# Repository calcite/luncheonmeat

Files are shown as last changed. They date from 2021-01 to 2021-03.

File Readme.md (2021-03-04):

# luncheonmeat

## Hardware

Device PCB was designed using KiCAD 5.1. For more info visit KiCAD website [kicad.org](https://kicad.org/download/) 

## Firmware

### Dependencies

```shell
sudo apt-get install gcc-avr binutils-avr avr-libc gdb-avr avrdude
```

> Note: ``ATMega328PB`` is new revision from 2017. avr-libc may not have support for this device. To add support please see how its done in .devcontainer/Dockerfile.

### Build

```shell
cd firmware
make
```

### Flashing

Flashing the device using AVR Dragon ISP:

```shell
make program
```

Set fuses **this is done only once**:

```shell
make program-fuses
```

> Note: ``make`` will internally run ``avrdude`` with correct atributes. 

Bare avrdude flashing command:

```shell
avrdude -p atmega328pb -P usb -c dragon_isp    -U flash:w:luncheonmeat.hex -U eeprom:w:luncheonmeat.eep
```

### Serial Bootloader

Generating ``defines.h`` file:
```shell
cd firmware/bootloader
./preprocessor.sh atmega328pb 2048 PORTB PINB0 8000000 19200
make
make program
make program-fuses
```

Reading target fuses:
```shell
avrdude -p atmega328pb -P usb -c dragon_isp -U efuse:r:-:h
```

To enter bootloader hold ''5'' button and reset the device.

## Resources

- [fuses calculator](http://eleccelerator.com/fusecalc/fusecalc.php?chip=atmega328p&LOW=E2&HIGH=D8&EXTENDED=F7&LOCKBIT=FF)

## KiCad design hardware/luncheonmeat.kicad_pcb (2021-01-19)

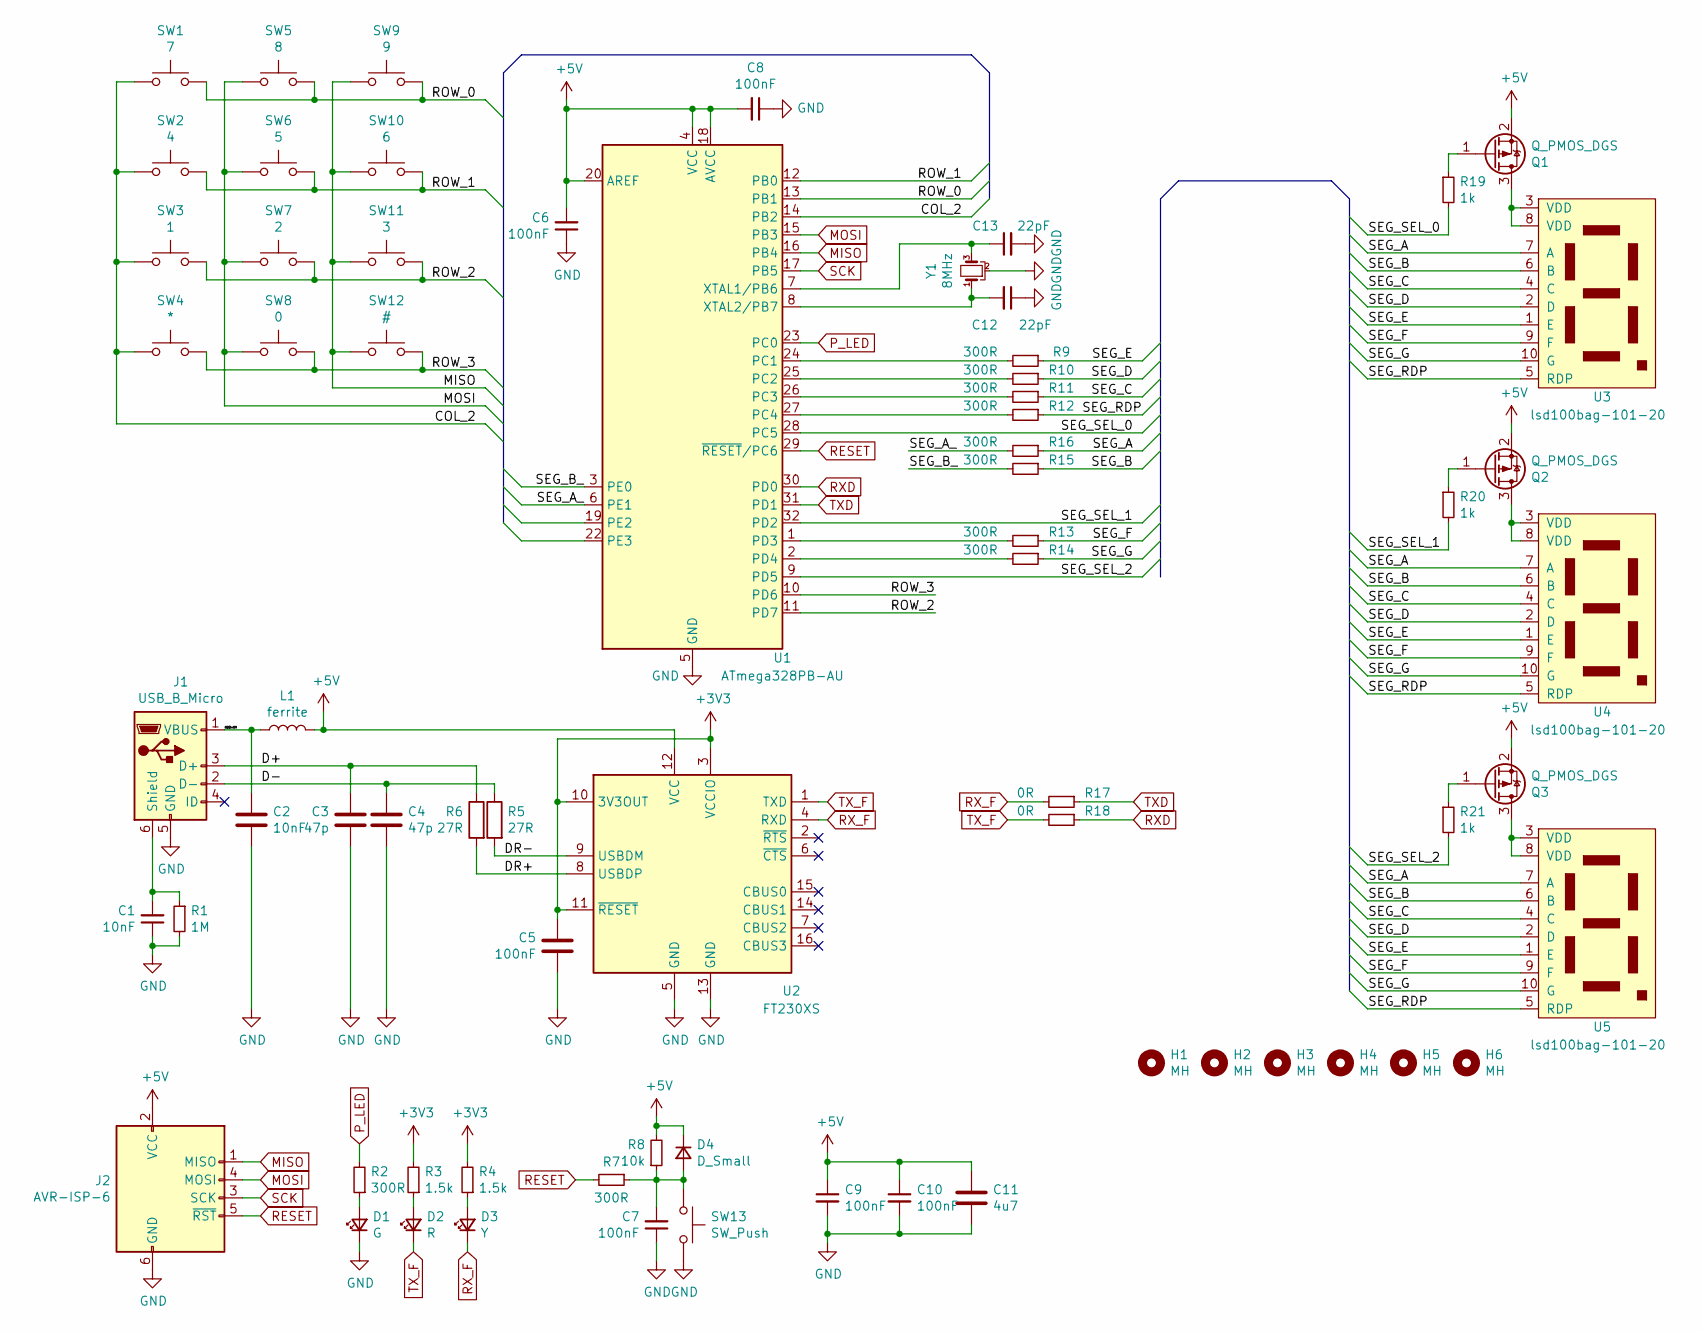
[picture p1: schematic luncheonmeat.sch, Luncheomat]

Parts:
C1, C2: 10nF; C_0805_2012Metric_Pad1.18x1.45mm_HandSolder
C3, C4: 47p; C_0805_2012Metric_Pad1.18x1.45mm_HandSolder
C5, C6, C7, C8, C9, C10: 100nF; C_0805_2012Metric_Pad1.18x1.45mm_HandSolder
C11: 4u7; C_0603_1608Metric_Pad1.05x0.95mm_HandSolder
C12, C13: 22pF; C_0603_1608Metric_Pad1.08x0.95mm_HandSolder
D1: G; LED_0805_2012Metric_Castellated
D2: R; LED_0805_2012Metric_Castellated
D3: Y; LED_0805_2012Metric_Castellated
D4: D_Small; D_0805_2012Metric
H1, H2, H3, H4, H5, H6: MH; MountingHole_3.2mm_M3_DIN965
J1: USB_B_Micro; USB_Micro-B_Wuerth_629105150521_CircularHoles
J2: AVR-ISP-6; IDC-Header_2x03_P2.54mm_Vertical
L1: ferrite; L_0805_2012Metric_Pad1.15x1.40mm_HandSolder
Q1, Q2, Q3: Q_PMOS_DGS; SOT-23
R1: 1M; R_0805_2012Metric_Pad1.20x1.40mm_HandSolder
R2, R7, R9, R10, R11, R12, R13, R14, R15, R16: 300R; R_0805_2012Metric_Pad1.20x1.40mm_HandSolder
R3, R4: 1.5k; R_0805_2012Metric_Pad1.20x1.40mm_HandSolder
R5, R6: 27R; R_0805_2012Metric_Pad1.20x1.40mm_HandSolder
R8: 10k; R_0805_2012Metric_Pad1.20x1.40mm_HandSolder
R17, R18: 0R; R_0805_2012Metric_Pad1.20x1.40mm_HandSolder
R19, R20, R21: 1k; R_0805_2012Metric_Pad1.20x1.40mm_HandSolder
SW1: 7; SW_PUSH_6mm
SW2: 4; SW_PUSH_6mm
SW3: 1; SW_PUSH_6mm
SW4: *; SW_PUSH_6mm
SW5: 8; SW_PUSH_6mm
SW6: 5; SW_PUSH_6mm
SW7: 2; SW_PUSH_6mm
SW8: 0; SW_PUSH_6mm
SW9: 9; SW_PUSH_6mm
SW10: 6; SW_PUSH_6mm
SW11: 3; SW_PUSH_6mm
SW12: #; SW_PUSH_6mm
SW13: SW_Push; SW_Push_1P1T_NO_CK_KSC7xxJ
U1: ATmega328PB-AU; TQFP-32_7x7mm_P0.8mm
U2: FT230XS; SSOP-16_3.9x4.9mm_P0.635mm
U3, U4, U5: lsd100bag-101-20; lsd100bag-101
Y1: 8MHz; Crystal_SMD_0603-4Pin_6.0x3.5mm_HandSoldering

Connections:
+3V3: C5.2, R3.2, R4.2, U2.3 (VCCIO), U2.10 (3V3OUT), U2.11 (~RESET)
+5V: C6.2, C8.2, C9.1, C10.1, C11.1, D4.1 (K), J2.2 (VCC), L1.2, Q1.2 (S), Q2.2 (S), Q3.2 (S), R8.2, U1.4 (VCC), U1.18 (AVCC), U1.20 (AREF), U2.12 (VCC)
/COL_2: SW1.2, SW2.2, SW3.2, SW4.2, U1.14 (PB2)
/D+: C3.2, J1.3 (D+), R6.1
/D-: C4.1, J1.2 (D-), R5.1
/DR+: R6.2, U2.8 (USBDP)
/DR-: R5.2, U2.9 (USBDM)
/ROW_0: SW1.1, SW5.1, SW9.1, U1.13 (PB1)
/ROW_1: SW2.1, SW6.1, SW10.1, U1.12 (PB0)
/ROW_2: SW3.1, SW7.1, SW11.1, U1.11 (PD7)
/ROW_3: SW4.1, SW8.1, SW12.1, U1.10 (PD6)
/SEG_A: R16.1, U3.7 (A), U4.7 (A), U5.7 (A)
/SEG_A_: R16.2, U1.6 (PE1)
/SEG_B: R15.1, U3.6 (B), U4.6 (B), U5.6 (B)
/SEG_B_: R15.2, U1.3 (PE0)
/SEG_C: R11.1, U3.4 (C), U4.4 (C), U5.4 (C)
/SEG_D: R10.1, U3.2 (D), U4.2 (D), U5.2 (D)
/SEG_E: R9.1, U3.1 (E), U4.1 (E), U5.1 (E)
/SEG_F: R13.1, U3.9 (F), U4.9 (F), U5.9 (F)
/SEG_G: R14.1, U3.10 (G), U4.10 (G), U5.10 (G)
/SEG_RDP: R12.1, U3.5 (RDP), U4.5 (RDP), U5.5 (RDP)
/SEG_SEL_0: R19.2, U1.28 (PC5)
/SEG_SEL_1: R20.2, U1.32 (PD2)
/SEG_SEL_2: R21.2, U1.9 (PD5)
/USB+5V: C2.2, J1.1 (VBUS), L1.1
GND: C1.1, C2.1, C3.1, C4.2, C5.1, C6.1, C7.1, C8.1, C9.2, C10.2, C11.2, C12.1, C13.2, D1.1 (K), J1.5 (GND), J2.6 (GND), R1.2, SW13.2, U1.5 (GND), U1.21 (GND), U2.5 (GND), U2.13 (GND), Y1.2
MISO: J2.1 (MISO), SW9.2, SW10.2, SW11.2, SW12.2, U1.16 (PB4)
MOSI: J2.4 (MOSI), SW5.2, SW6.2, SW7.2, SW8.2, U1.15 (PB3)
unnamed: C1.2, J1.6 (Shield), R1.1
unnamed: C7.2, D4.2 (A), R7.1, R8.1, SW13.1
unnamed: C12.2, U1.8 (XTAL2/PB7), Y1.1
unnamed: C13.1, U1.7 (XTAL1/PB6), Y1.3
unnamed: D1.2 (A), R2.1
unnamed: D2.2 (A), R3.1
unnamed: D3.2 (A), R4.1
unnamed: Q1.1 (G), R19.1
unnamed: Q1.3 (D), U3.3 (VDD), U3.8 (VDD)
unnamed: Q2.1 (G), R20.1
unnamed: Q2.3 (D), U4.3 (VDD), U4.8 (VDD)
unnamed: Q3.1 (G), R21.1
unnamed: Q3.3 (D), U5.3 (VDD), U5.8 (VDD)
unnamed: R9.2, U1.24 (PC1)
unnamed: R10.2, U1.25 (PC2)
unnamed: R11.2, U1.26 (PC3)
unnamed: R12.2, U1.27 (PC4)
unnamed: R13.2, U1.1 (PD3)
unnamed: R14.2, U1.2 (PD4)
P_LED: R2.2, U1.23 (PC0)
RESET: J2.5 (~RST), R7.2, U1.29 (~RESET~/PC6)
RXD: R18.1, U1.30 (PD0)
RX_F: D3.1 (K), R17.2, U2.4 (RXD)
SCK: J2.3 (SCK), U1.17 (PB5)
TXD: R17.1, U1.31 (PD1)
TX_F: D2.1 (K), R18.2, U2.1 (TXD)

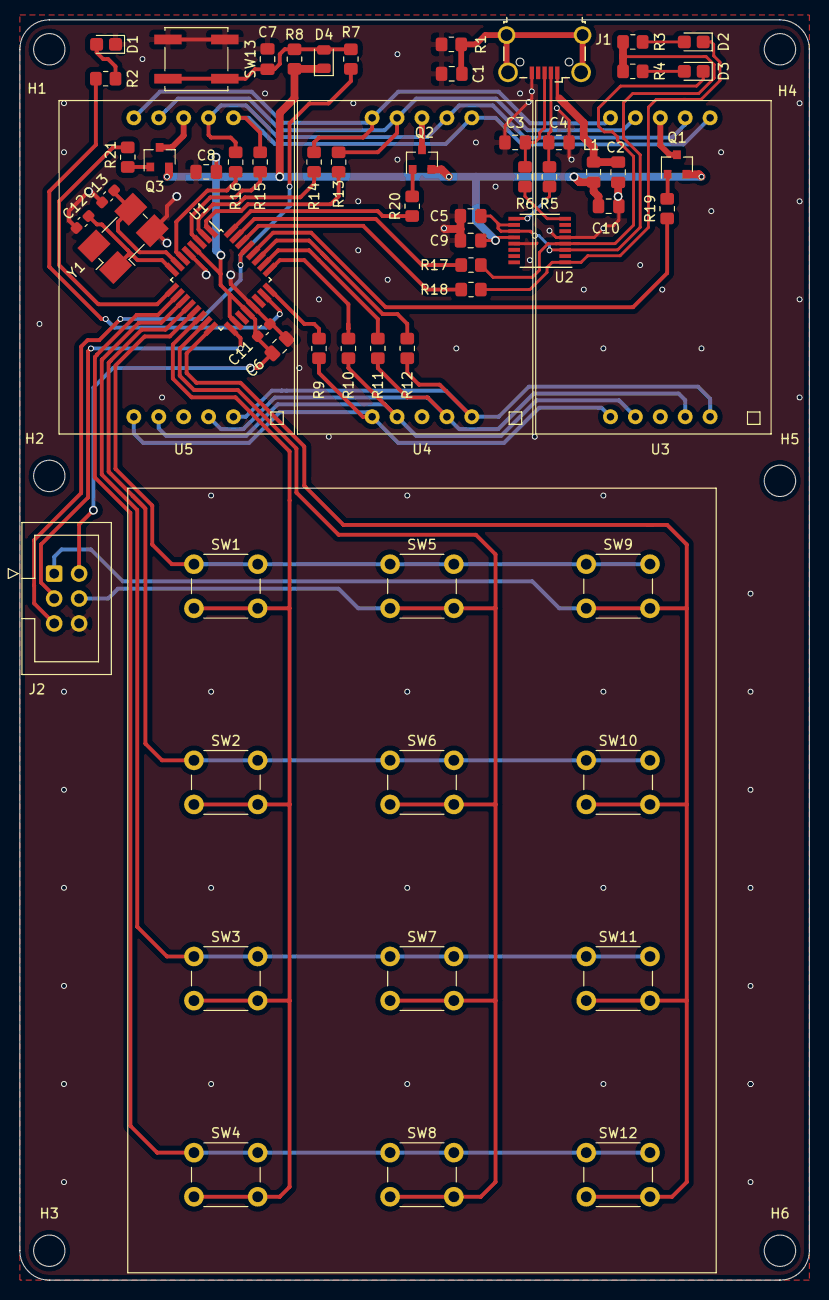
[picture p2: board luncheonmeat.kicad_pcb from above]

Board: 2 copper layers, 80.5 x 128.5 mm, 69 parts (0 on the bottom side), 54 nets.

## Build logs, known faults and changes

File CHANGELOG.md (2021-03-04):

# CHANGELOG

## v0.4.4 [2021/03/04]

- added AVR109 bootloader.

## v0.4.3 [2021/03/04]

- allow to send single zero.
- add clear command send on clear button long push.

## v0.4.2 [2021/03/03]

- fix zero imput handling, when zero is imputed as first character.

## v0.4.1 [2021/02/22]

- fix multiplex for animations and special characters.

## v0.4.0 [2021/02/22]

- segments inverted to back side.
- keypad mapping changed to mobile phone layout.
- maximum of 3 digits can be imputed at the time. (There is no owerflow)
- variable single digit multiplex to increase brightness.

## v0.3.0 [2021/02/18]

First firmware release. This release includes:

- 7 segment display driver.
- key matrix readout.
- USART driver and simple transport packet format.
- Coplete startup and device operation.

## v0.2.4 [2021/01/19]

- button alignment.

## v0.2.3 [2021/01/19]

- move 7-segments together.
- generate step file for case design.

## v0.2.2 [2021/01/15]

- Fix P-MOS driver transistors connections.
- Confirm 7-segmet parts.

## v0.2.1 [2021/01/08]

- Fix usb data lines connection

## v0.2.0 [2020/12/22]

- Fixed schematic.
- PCB design completed.
- Gerber files generated.

## v0.1.0 [2020/12/21]

- Taken over by Juraj.
- Created files structure.

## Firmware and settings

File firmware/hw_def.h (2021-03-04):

/*
 *  Copyright (C) 2021 Juraj Giertl
 *  All Rights Reserved.
 */
#ifndef _HW_DEF_H_
#define _HW_DEF_H_

#include <avr/version.h>

#define HW_VER_TAG "v0.2.4"
#define SW_VER_TAG "v0.4.4"
#define COMMENT "Luncheonmeat (" SW_VER_TAG "). "              \
                "Simple keypad controle device with display. " \
                "Compiled: " __DATE__ ", " __TIME__ ". "       \
                "Using AVR LIBC (" __AVR_LIBC_VERSION_STRING__ ")."

#define LED_G PC0
#define LED_PORT PORTC
#define LED_DDR DDRC

#define LEDG_OFF LED_PORT &= ~(1 << LED_G);
#define LEDG_ON LED_PORT |= (1 << LED_G);

#define MATRIX_LAYPUT_PHONE_INVERTED

#define SEG_DISPLAY_INVERTED
#define SEG_DISPALY_SINGLE_DIGIT_OPT

void io_init(void);

#endif // HW_DEF_H

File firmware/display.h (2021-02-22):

/*
 *  Copyright (C) 2017 Juraj Giertl
 *  All Rights Reserved.
 */
#ifndef _DISPLAY_H_
#define _DISPLAY_H_

#include "hw_def.h"

#define SEG_DISPALY_N_SEGS (3)

#ifdef SEG_DISPLAY_INVERTED
#define seg_a		2//7
#define seg_b		1//6
#define seg_c		4//5
#define seg_d		5//4
#define seg_e		0//3
#define seg_f		7//2
#define seg_g		6//1
#define seg_dp		3//0

/* Segment multiplexing */
#define SEG_POS_0              2
#define SEG_POS_1              1
#define SEG_POS_2              0

#else

#define seg_a		7
#define seg_b		6
#define seg_c		5
#define seg_d		4
#define seg_e		3
#define seg_f		2
#define seg_g		1
#define seg_dp		0

/* Segment multiplexing */
#define SEG_POS_0              0
#define SEG_POS_1              1
#define SEG_POS_2              2
#endif

#define A		0
#define N		1


#define SEG_A_PIN		PINE1
#define SEG_B_PIN		PINE0
#define SEG_C_PIN		PINC3
#define SEG_D_PIN		PINC2
#define SEG_E_PIN		PINC1
#define SEG_F_PIN		PIND3
#define SEG_G_PIN		PIND4
#define SEG_DP_PIN		PINC4

#define SEG_A_DDR		DDRE
#define SEG_B_DDR		DDRE
#define SEG_C_DDR		DDRC
#define SEG_D_DDR		DDRC
#define SEG_E_DDR		DDRC
#define SEG_F_DDR		DDRD
#define SEG_G_DDR		DDRD
#define SEG_DP_DDR		DDRC

#define SEG_A_PORT      PORTE
#define SEG_B_PORT      PORTE
#define SEG_C_PORT      PORTC
#define SEG_D_PORT      PORTC
#define SEG_E_PORT      PORTC
#define SEG_F_PORT      PORTD
#define SEG_G_PORT      PORTD
#define SEG_DP_PORT     PORTC


#define SEG_POS_0_DDR          DDRC
#define SEG_POS_0_PORT         PORTC
#define SEG_POS_0_PIN          PINC5

#define SEG_POS_1_DDR          DDRD
#define SEG_POS_1_PORT         PORTD
#define SEG_POS_1_PIN          PIND2

#define SEG_POS_2_DDR          DDRD
#define SEG_POS_2_PORT         PORTD  
#define SEG_POS_2_PIN          PIND5

#define SEG_DISP_CHAR_CLEAR    (0xFF) // 0xFF

static uint8_t __attribute__((used)) seg_display_chars[18] =
{
	(A << seg_a) | (A << seg_b) | (A << seg_c) | (A << seg_d) | (A << seg_e) | (A << seg_f) | (N << seg_g) | (N << seg_dp),//0
	(N << seg_a) | (A << seg_b) | (A << seg_c) | (N << seg_d) | (N << seg_e) | (N << seg_f) | (N << seg_g) | (N << seg_dp),//1
	(A << seg_a) | (A << seg_b) | (N << seg_c) | (A << seg_d) | (A << seg_e) | (N << seg_f) | (A << seg_g) | (N << seg_dp),//2
	(A << seg_a) | (A << seg_b) | (A << seg_c) | (A << seg_d) | (N << seg_e) | (N << seg_f) | (A << seg_g) | (N << seg_dp),//3
	(N << seg_a) | (A << seg_b) | (A << seg_c) | (N << seg_d) | (N << seg_e) | (A << seg_f) | (A << seg_g) | (N << seg_dp),//4
	(A << seg_a) | (N << seg_b) | (A << seg_c) | (A << seg_d) | (N << seg_e) | (A << seg_f) | (A << seg_g) | (N << seg_dp),//5
	(A << seg_a) | (N << seg_b) | (A << seg_c) | (A << seg_d) | (A << seg_e) | (A << seg_f) | (A << seg_g) | (N << seg_dp),//6
	(A << seg_a) | (A << seg_b) | (A << seg_c) | (N << seg_d) | (N << seg_e) | (N << seg_f) | (N << seg_g) | (N << seg_dp),//7
	(A << seg_a) | (A << seg_b) | (A << seg_c) | (A << seg_d) | (A << seg_e) | (A << seg_f) | (A << seg_g) | (N << seg_dp),//8
	(A << seg_a) | (A << seg_b) | (A << seg_c) | (A << seg_d) | (N << seg_e) | (A << seg_f) | (A << seg_g) | (N << seg_dp),//9
	(A << seg_a) | (A << seg_b) | (A << seg_c) | (N << seg_d) | (A << seg_e) | (A << seg_f) | (A << seg_g) | (N << seg_dp),//A ,10
	(A << seg_a) | (A << seg_b) | (A << seg_c) | (A << seg_d) | (A << seg_e) | (A << seg_f) | (A << seg_g) | (N << seg_dp),//B ,11
	(A << seg_a) | (N << seg_b) | (N << seg_c) | (A << seg_d) | (A << seg_e) | (A << seg_f) | (N << seg_g) | (N << seg_dp),//C ,12
	(A << seg_a) | (A << seg_b) | (A << seg_c) | (A << seg_d) | (A << seg_e) | (A << seg_f) | (N << seg_g) | (N << seg_dp),//D ,13
	(A << seg_a) | (N << seg_b) | (N << seg_c) | (A << seg_d) | (A << seg_e) | (A << seg_f) | (A << seg_g) | (N << seg_dp),//E ,14
	(A << seg_a) | (N << seg_b) | (N << seg_c) | (N << seg_d) | (A << seg_e) | (A << seg_f) | (A << seg_g) | (N << seg_dp),//F ,15
	(A << seg_a) | (A << seg_b) | (N << seg_c) | (N << seg_d) | (N << seg_e) | (A << seg_f) | (A << seg_g) | (N << seg_dp),//degree
	(N << seg_a) | (N << seg_b) | (N << seg_c) | (N << seg_d) | (N << seg_e) | (N << seg_f) | (A << seg_g) | (N << seg_dp),//minus

};

void seg_display_wait_animation(uint8_t from, uint8_t to, uint16_t speed);

void seg_dispaly_set_digits(uint8_t d2, uint8_t d1, uint8_t d0);
void seg_dispaly_set_dec_num(uint16_t num);

void seg_display_draw_circle(void);
void seg_display_draw_line(void);
void seg_display_clear(void);

void seg_display_set_contrast(uint8_t val);

void seg_display_init(void);

#endif

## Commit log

2020-10-08 pushing it all
    [luncheonmeat.kicad_pcb, luncheonmeat.sch]
2020-12-21 v0.1.0 Initial release to ALCZ git. Created file structures.
    [luncheonmeat.kicad_pcb, luncheonmeat.sch]
2020-12-21 Fix schematic, new board layout
    [luncheonmeat.kicad_pcb, luncheonmeat.sch]
2020-12-22 v0.2.0, PCB board finished
    [luncheonmeat-B_Cu.gbr, luncheonmeat-B_Mask.gbr, luncheonmeat-B_Paste.gbr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]
2021-01-08 v0.2.1 PCB Updated
    [luncheonmeat-B_Cu.gbr, luncheonmeat-B_Mask.gbr, luncheonmeat-B_Paste.gbr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]
2021-01-15 v0.2.2 PCB Updated
    [luncheonmeat-B_Cu.gbr, luncheonmeat-B_Mask.gbr, luncheonmeat-B_Paste.gbr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]
2021-01-19 v0.2.3 PCB Updated, board step file generated
    [luncheonmeat-B_Cu.gbr, luncheonmeat-B_Mask.gbr, luncheonmeat-B_Paste.gbr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]
2021-01-19 v0.2.4 PCB Updated
    [luncheonmeat-B_Cu.gbr, luncheonmeat-B_Mask.gbr, luncheonmeat-B_Paste.gbr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]
2021-01-25 [ADD] support for atmega328pb device
2021-02-22 Release v0.4.1 fix multiplex
    [display.h, hw_def.h]
